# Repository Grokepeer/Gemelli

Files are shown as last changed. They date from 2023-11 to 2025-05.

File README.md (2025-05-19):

# Gemelli

A split keyboard with 58 keys, 2 encoders, 2 I<sup>2</sup>C displays and type C removable cables. The two boards are powered by two STM32F446. The two uC are connected together by an SPI line (through a USB C to USB C cable) to allow faster transmission rates for the displays. The firmware is completely custom, written in C but the board should support QMK's firmware aswell.

## PCB 2D Renderings

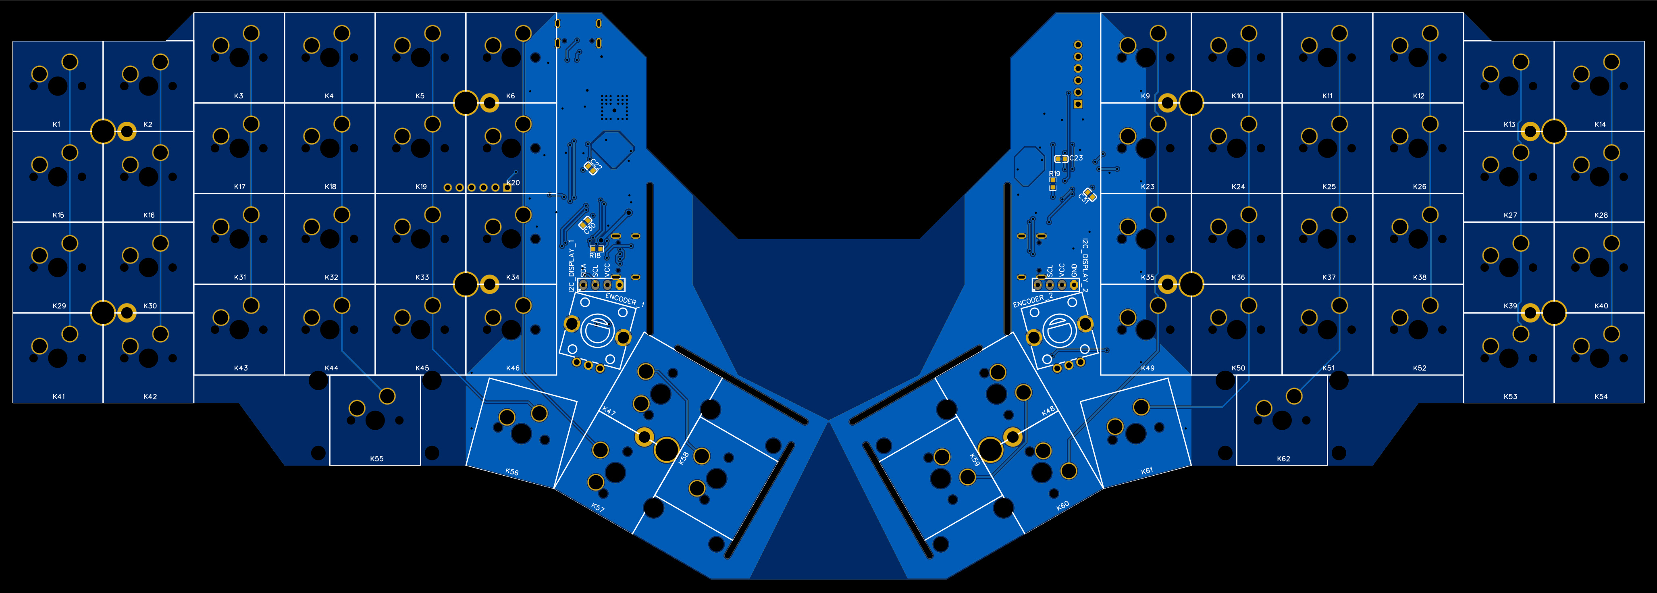
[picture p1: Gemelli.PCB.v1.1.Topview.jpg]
Top view


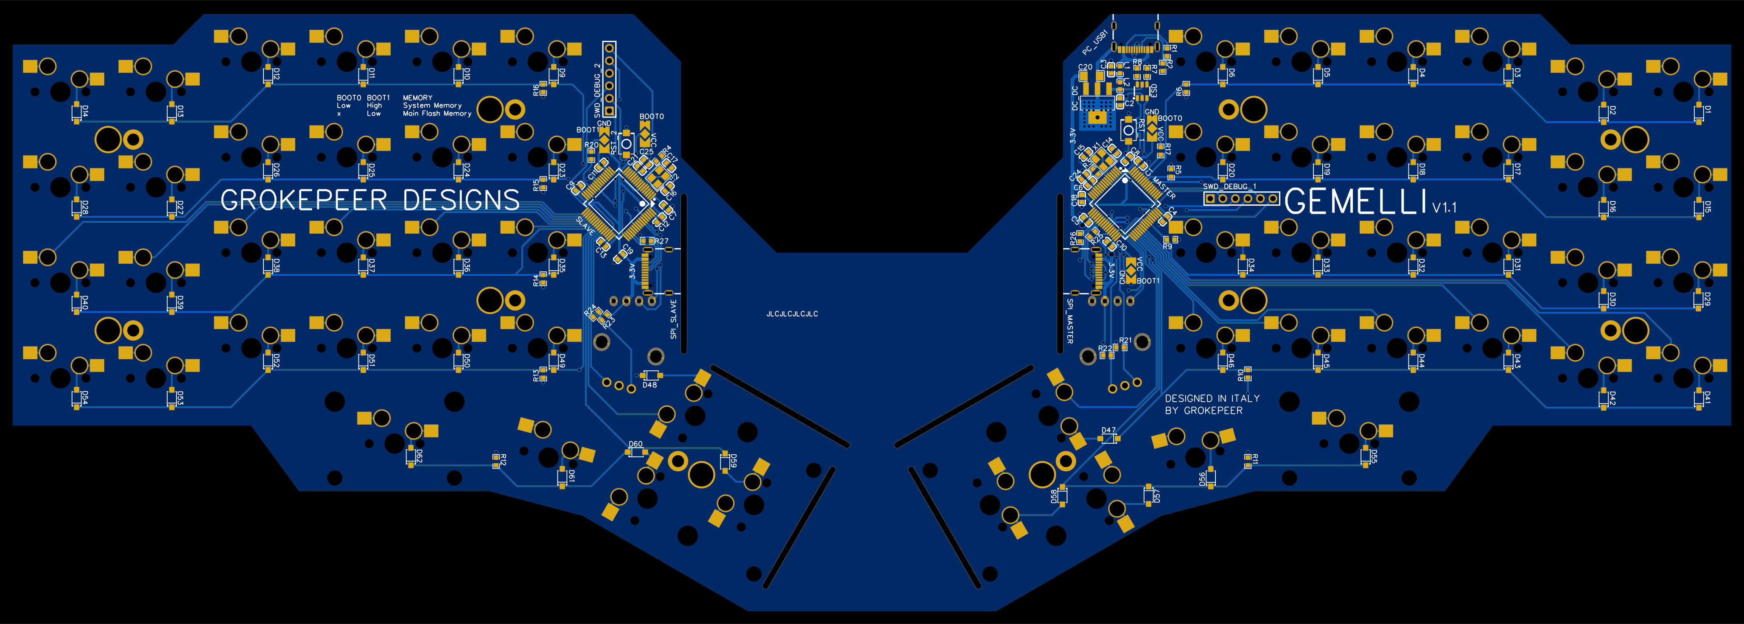
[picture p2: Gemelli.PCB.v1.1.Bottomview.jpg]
Bottom view


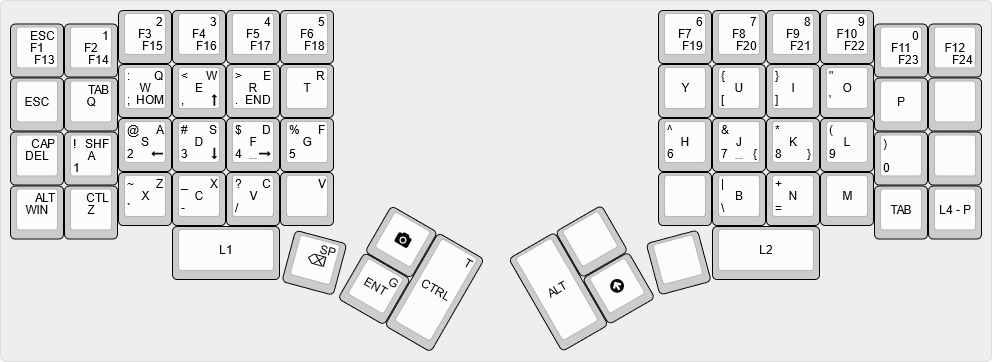
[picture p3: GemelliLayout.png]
Key layout


## Key Layout and Layers

The baked-in key layout on the custom firmware is as above. Note that the keyboard utilizes the multiple "layers" principle common to compact keyboard such as this one. In the middle of a key you will se the standard layer keybind, in the upper left corner the L1+shift, in the lower left the L1, in the lower right L2 while in the upper right corner is the L4. All layers except L4 are press-and-hold while L4 is a toggle layer that you can exit pressing L1+L2.

**To modify the layout** you can modify the maps in the master uC code and flash the updated firmware. Alternatively you can flash QMK and use their USB on-the-fly reprogramming to change layout.

## V2.0 Upgrades

This was one of the first PCB I designed, looking back I see many mistakes I made, some might not cause any problem, others should better be fixed:

- Redesign PCB paneling
- Remove ground pour from the breakable supports
- Add new debugging connectors
- Remove encoders
- Move mounting points from the plate to the PCB
- Firmware overhaul

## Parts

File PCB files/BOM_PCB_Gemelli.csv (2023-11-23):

ID | Name | Designator | Footprint | Quantity | Manufacturer Part | Manufacturer | Supplier | Supplier Part | Price
1 | EC12E24204A2 | ENCODER_1,ENCODER_2 | SW-TH_EC12E24204A2 | 2 | EC12E24204A2 | ALPS Electric | LCSC | C351238 | 0.848
2 | 4.7uF | C31,C30 | C0603 | 2 | CSA0603X5R475K6R3JT | HRE(芯声) | LCSC | C3015159
3 | 10kΩ | R19,R18,R23,R24,R21,R22,R20,R17,R5,R6,R9,R10,R11,R12,R13,R14,R15,R16 | R0603 | 18 | 0603WAF1002T5E | UNI-ROYAL(厚声) | LCSC | C25804 | 0.001
4 | 100nF | C22,C23,C7,C21,C9,C11,C12,C13,C4,C8,C10,C5,C6,C1 | C0603 | 14 | CC0603KRX7R9BB104 | YAGEO(国巨) | LCSC | C14663 | 0.002
5 | STM32F446RET6 | MASTER,SLAVE | LQFP-64_L10.0-W10.0-P0.50-LS12.0-BL | 2 | STM32F446RET6 | ST(意法半导体) | LCSC | C69336 | 4.087
6 | USB-TYPE-C-017 | SPI_MASTER,SPI_SLAVE,PC_USB1 | USB-TYPE-C-SMD_C9900008089 | 3 | USB-TYPE-C-017 | DEALON(德艺隆) | LCSC | C2927037 | 0.117
7 | 22Ω | R25,R26,R27,R7,R8 | R0603 | 5 | 0603WAF220JT5E | UNI-ROYAL(厚声) | LCSC | C23345 | 0.001
8 | 1uF | C24,C25 | C0603 | 2 | CC0603KRX7R7BB105 | YAGEO(国巨) | LCSC | C106248 | 0.008
9 | Ferrite Beads | L1,L2 | L0603 | 2 | BLM18PG121SN1D | muRata(村田) | LCSC | C14709 | 0.006
10 | LM3940IMP-3.3/NOPB | DC_DC | SOT-223_L6.5-W3.5-P2.30-LS7.0-BR | 1 | LM3940IMP-3.3/NOPB | TI(德州仪器) | LCSC | C140319 | 1.653
11 | TS-1088-AR02016 | RST_1,RST_2 | SW-SMD_L3.9-W3.0-P4.45 | 2 | TS-1088-AR02016 | XUNPU(讯普) | LCSC | C720477 | 0.045
12 | TPUSBLC6-2SC6 | ESD | SOT-23-6_L2.9-W1.6-P0.95-LS2.8-BR | 1 | TPUSBLC6-2SC6 | TECH PUBLIC(台舟) | LCSC | C558442 | 0.074
13 | 10uF | C19,C18,C2,C3 | C0603 | 4 | CL10A106MA8NRNC | SAMSUNG(三星) | LCSC | C96446 | 0.021
14 | 14pF | C17,C14,C15,C16 | C0603 | 4 | CL10C140JB8NNNC | SAMSUNG(三星) | LCSC | C170136
15 | 47uF | C20 | C1206 | 1 | GRM31CR61A476ME15L | muRata(村田) | LCSC | C94034 | 0.061
16 | 715Ω | R3,R4 | R0603 | 2 | CR0603FA7150G | LIZ(丽智电子) | LCSC | C101173 | 0.001
17 | 16MHz | X1,X2 | CRYSTAL-SMD_4P-L3.2-W2.5-BL | 2 | X322516MOB4SI | YXC(扬兴晶振) | LCSC | C12668 | 0.066
18 | 5.1kΩ | R1,R2 | R0603 | 2 | RTT03512JTP | RALEC(旺诠) | LCSC | C103696 | 0.001
19 | 1N4148W_C81598 | D1,D2,D3,D4,D5,D6,D9,D10,D11,D12,D13,D14,D15,D16,D17,D18,D19,D20,D23,D24,D25,D26,D27,D28,D29,D30,D31,D32,D33,D34,D35,D36,D37,D38,D39,D40,D41,D42,D43,D44,D45,D46,D47,D48,D49,D50,D51,D52,D53,D54,D55,D56,D57,D58,D59,D60,D61,D62 | SOD-123F_L2.7-W1.6-LS3.8-RD | 58 | 1N4148W | ST(先科) | LCSC | C81598 | 0.007

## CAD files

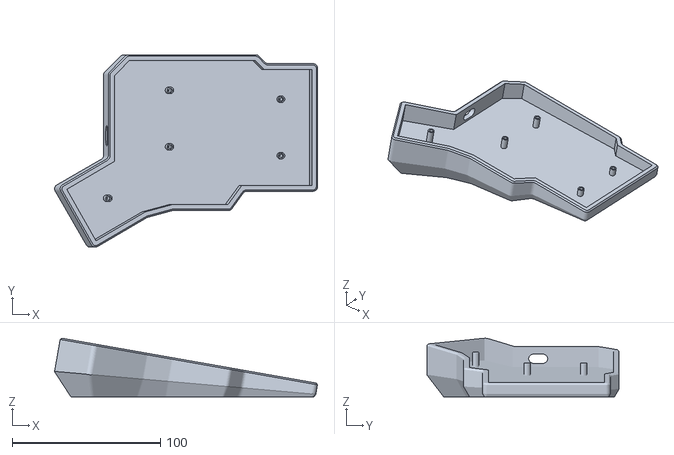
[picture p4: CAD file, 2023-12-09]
3D files/Gemelli Case R v7.stl
177.6 x 130.0 x 39.5

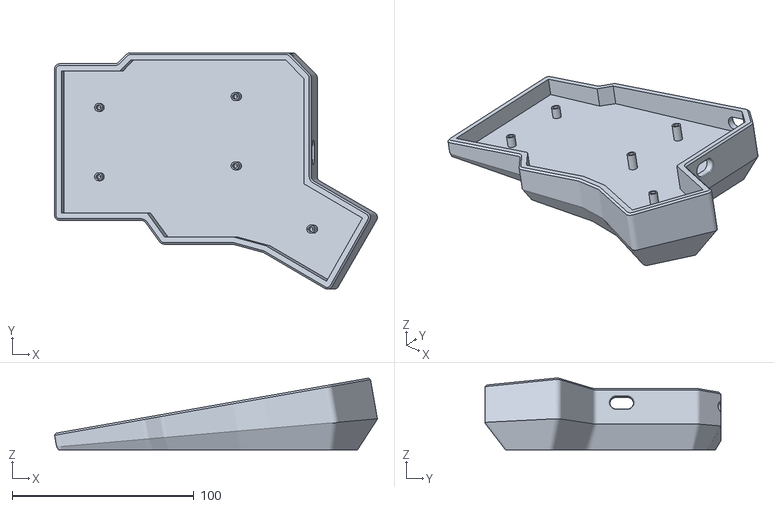
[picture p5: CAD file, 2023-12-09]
3D files/Gemelli Case L v8.stl
177.6 x 130.0 x 39.5

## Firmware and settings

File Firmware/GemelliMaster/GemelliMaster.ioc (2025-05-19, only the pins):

Mcu.UserName=STM32F446RETx
PA11.Signal=USB_OTG_FS_DM
PA12.Signal=USB_OTG_FS_DP
PA13.Signal=SYS_JTMS-SWDIO
PA14.Signal=SYS_JTCK-SWCLK
PA5.Signal=SPI1_SCK
PA6.Signal=SPI1_MISO
PA7.Signal=SPI1_MOSI
PA9.Signal=GPIO_Input
PB0.Signal=GPIO_Input
PB1.Signal=GPIO_Input
PB12.Signal=GPIO_Output
PB13.Signal=GPIO_Output
PB14.Signal=GPIO_Output
PB15.Signal=GPIO_Output
PB5.Signal=GPIO_Input
PB6.Signal=GPIO_Input
PC4.GPIO_Label=Rotary_DT
PC4.Signal=GPIO_Input
PC5.GPIO_Label=Rotary_CLK
PC5.Signal=GPIO_Input
PC6.Signal=GPIO_Output
PC7.Signal=GPIO_Output
PC8.Signal=GPIO_Output
PH0-OSC_IN.Signal=RCC_OSC_IN
PH1-OSC_OUT.Signal=RCC_OSC_OUT

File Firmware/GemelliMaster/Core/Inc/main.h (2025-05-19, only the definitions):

#define Rotary_DT_Pin GPIO_PIN_4
#define Rotary_DT_GPIO_Port GPIOC
#define Rotary_CLK_Pin GPIO_PIN_5
#define Rotary_CLK_GPIO_Port GPIOC

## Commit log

2023-12-09 new case models
    [Gemelli Case L v8.stl, Gemelli Case R v7.stl]
2025-05-19 File reorganization
    [BOM_PCB_Gemelli.csv, Gemelli Case L v8.stl, Gemelli Case R v7.stl]
2025-05-19 PCB 2D renderings and README
2025-05-19 Added STM32 projects and updated README

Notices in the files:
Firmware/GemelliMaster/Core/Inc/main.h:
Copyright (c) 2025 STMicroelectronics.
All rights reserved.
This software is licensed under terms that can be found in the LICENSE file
